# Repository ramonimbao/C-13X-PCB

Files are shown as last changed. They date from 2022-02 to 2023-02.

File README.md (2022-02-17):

# C-13X-PCB

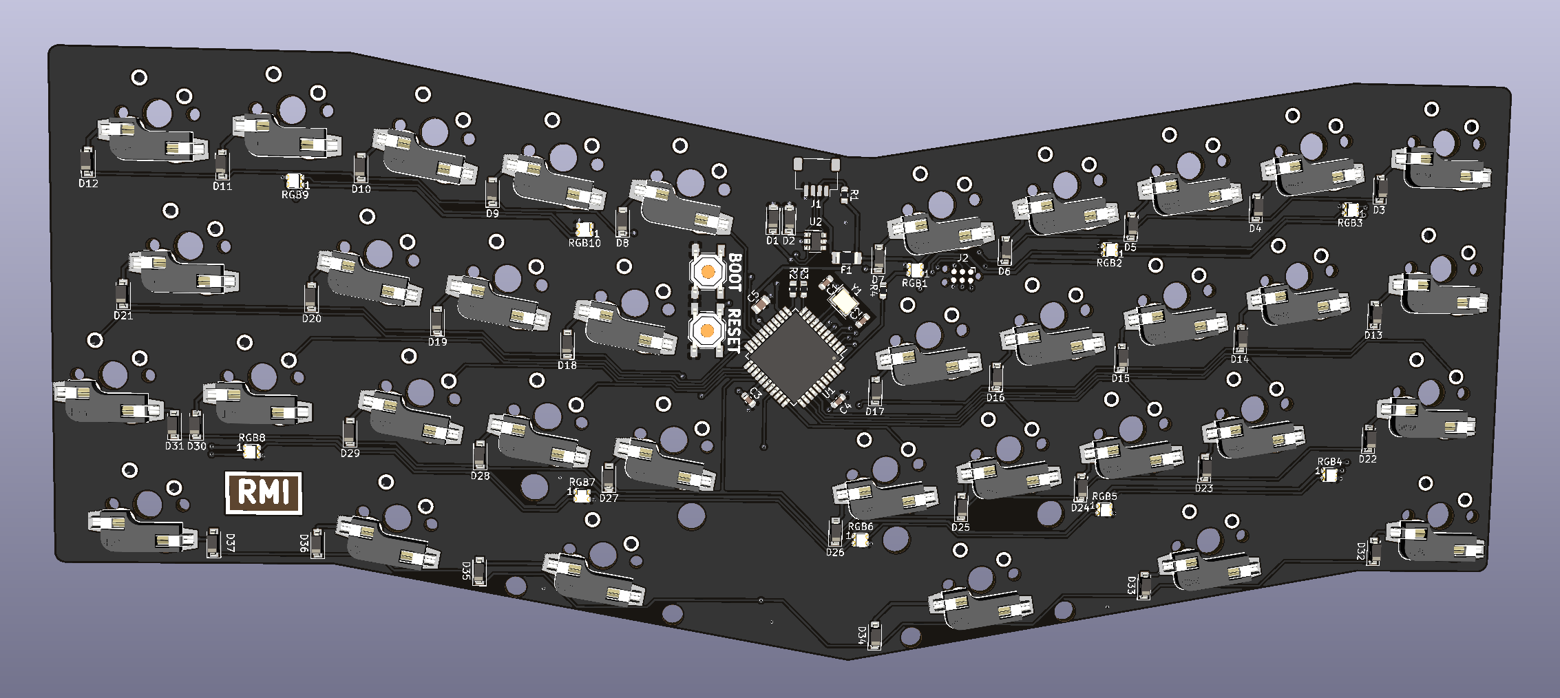
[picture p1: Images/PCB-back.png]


## Features

- ATmega32A
- ai03 daughterboard compatible
- Solder and Kailh hotswap compatible

## How to order

1. JLCPCB.com
2. Upload the gerber zip file from the `Gerbers` directory.
3. Select SMT assembly as an option.
4. Select the bottom side to assemble.
5. Upload the BOM and CPL files from the `JLCPCB` directory.
6. Place your order.
7. ???
8. Profit!

## After ordering

Once you've received the boards, you will have to flash a bootloader on it before being able to flash any QMK firmware on it.

Instructions for that can be found using [here](https://github.com/coseyfannitutti/discipline/blob/master/doc/bootloader/README.md).

## Flashing QMK firmware on it

TBD because I've yet to order boards for myself

## License

This has the same license as the C-13X. See the `LICENSE` file for more details.

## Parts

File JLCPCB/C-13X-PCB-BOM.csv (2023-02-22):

Comment | Designator | Footprint | LCSC
22pF | C1,C2 | Capacitor_SMD:C_0603_1608Metric | C1653
100nF | C3,C4 | Capacitor_SMD:C_0603_1608Metric | C14663
10uF | C5 | Capacitor_SMD:C_0805_2012Metric | C15850
3.6V | D1,D2 | Diode_SMD:D_SOD-123 | C2891771
1N4148W | D3,D4,D5,D6,D7,D8,D9,D10,D11,D12,D13,D14,D15,D16,D17,D18,D19,D20,D21,D22,D23,D24,D25,D26,D27,D28,D29,D30,D31,D32,D33,D34,D35,D36,D37 | Diode_SMD:D_SOD-123 | C81598
500mA | F1 | Fuse:Fuse_1206_3216Metric_Pad1.42x1.75mm_HandSolder | C69688
ai03_Daughterboard_Connector | J1 | Connector_JST:JST_SH_SM04B-SRSS-TB_1x04-1MP_P1.00mm_Horizontal | C160404
MX-NoLED | MX11,MX12,MX13,MX14,MX15,MX16,MX17,MX18,MX19,MX20,MX31,MX32,MX33,MX34,MX35,MX36,MX37,MX50,MX51,MX52,MX53,MX54,MX55,MX56,MX58,MX66,MX69 | MX_HS:MXOnly-1U-Hotswap-NoLED | C5156480
MX-NoLED | MX30,MX57 | MX_HS:MXOnly-1.25U-Hotswap-NoLED | C5156480
MX-NoLED | MX38,MX49 | MX_HS:MXOnly-1.75U-Hotswap-NoLED | C5156480
MX-NoLED | MX65,MX70 | MX_HS:MXOnly-1.5U-Hotswap-NoLED | C5156480
MX-NoLED | MX67 | MX_HS:MXOnly-2.75U-Hotswap-NoLED | C5156480
MX-NoLED | MX68 | MX_HS:MXOnly-2.25U-Hotswap-NoLED | C5156480
1.5k | R1 | Resistor_SMD:R_0603_1608Metric | C22843
75 | R2,R3 | Resistor_SMD:R_0603_1608Metric | C4275
470 | R4 | Resistor_SMD:R_0603_1608Metric | C23179
WS2812B-2020 | RGB1,RGB2,RGB3,RGB4,RGB5,RGB6,RGB7,RGB8,RGB9,RGB10 | random-keyboard-parts:WS2812B-2020 | C965555
SW_Push | SW1,SW2 | Button_Switch_SMD:SW_SPST_TL3342 | C318884
ATmega32A-AU | U1 | Package_QFP:TQFP-44_10x10mm_P0.8mm | C5659
SRV05-4 | U2 | Package_TO_SOT_SMD:SOT-23-6 | C85364
Crystal_GND24_Small | Y1 | Crystal:Crystal_SMD_3225-4Pin_3.2x2.5mm | C13738

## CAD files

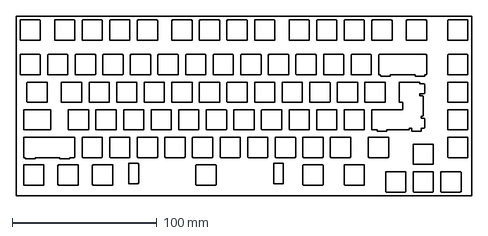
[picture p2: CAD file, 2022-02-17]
layout.dxf
314.3 x 123.8 mm

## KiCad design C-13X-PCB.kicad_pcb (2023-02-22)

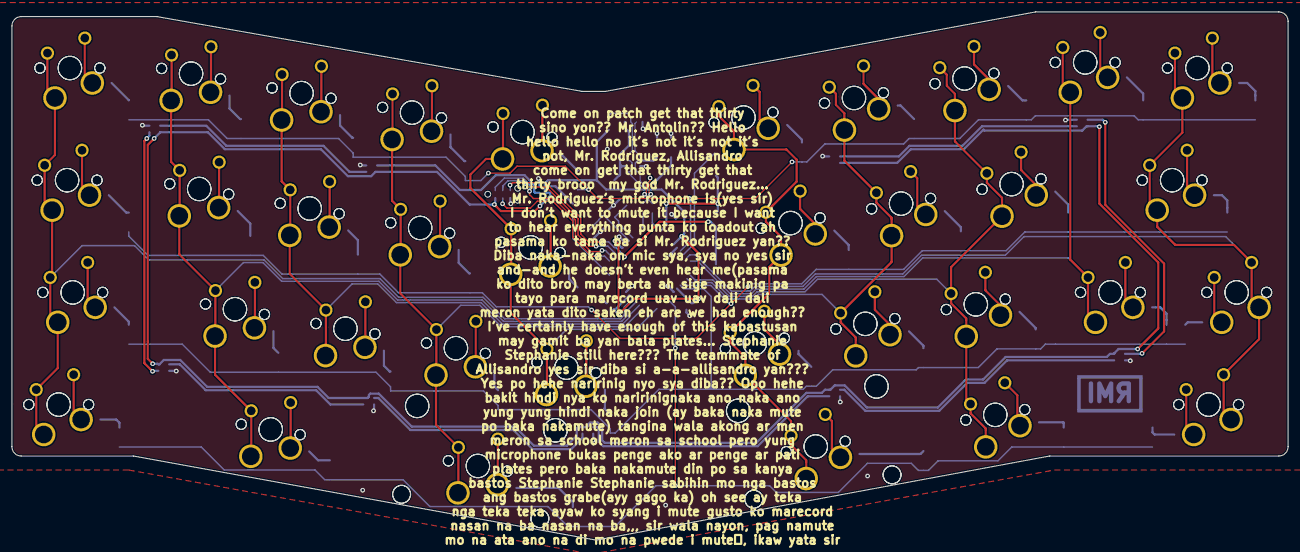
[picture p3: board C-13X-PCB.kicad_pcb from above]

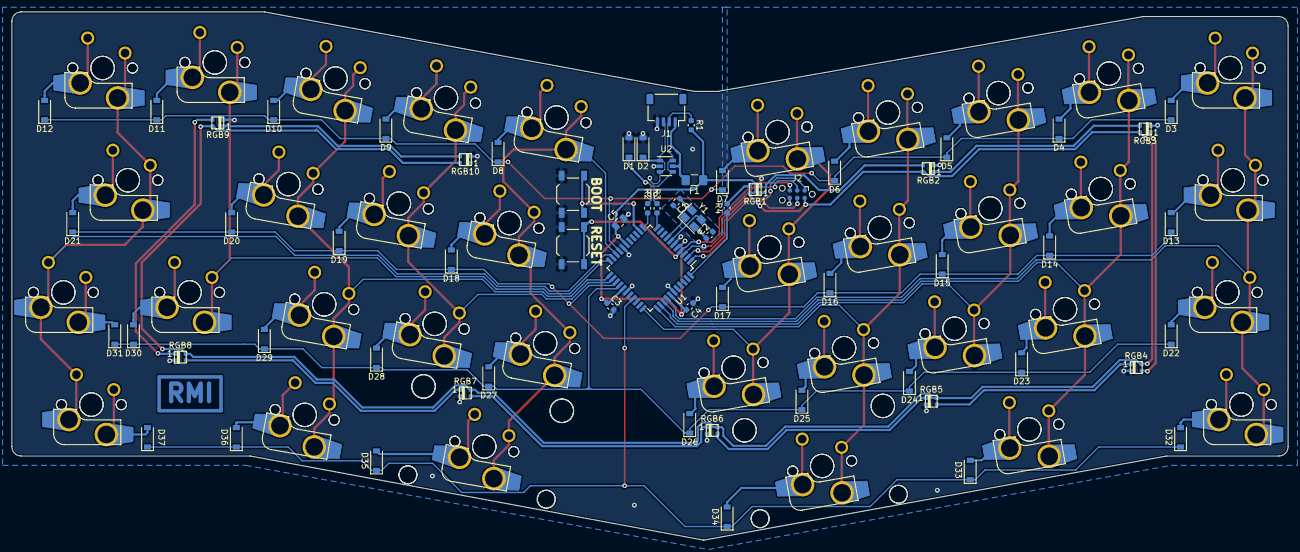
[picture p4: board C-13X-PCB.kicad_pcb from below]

Board: 2 copper layers, 216.7 x 89.7 mm, 135 parts (100 on the bottom side), 74 nets.

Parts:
C1, C2: 22pF; C_0603_1608Metric
C3, C4: 100nF; C_0603_1608Metric
C5: 10uF; C_0805_2012Metric
D1, D2: 3.6V; D_SOD-123
D3, D4, D5, D6, D7, D8, D9, D10, D11, D12, D13, D14, D15, D16, D17, D18, D19, D20, D21, D22, D23, D24, D25, D26, D27, D28, D29, D30, D31, D32, D33, D34, D35, D36, D37: 1N4148; D_SOD-123
F1: 500mA; Fuse_1206_3216Metric_Pad1.42x1.75mm_HandSolder
G1: Signature
J1: ai03_Daughterboard_Connector; JST_SH_SM04B-SRSS-TB_1x04-1MP_P1.00mm_Horizontal
J2: AVR-TagConnect; Tag-Connect_TC2030-IDC-NL_2x03_P1.27mm_Vertical
MX1, MX2, MX3, MX4, MX5, MX6, MX7, MX8, MX9, MX10, MX22, MX23, MX24, MX25, MX26, MX27, MX28, MX40, MX41, MX42, MX43, MX44, MX45, MX46, MX48, MX60, MX63: MX-NoLED; MXOnly-1U-NoLED
MX11, MX12, MX13, MX14, MX15, MX16, MX17, MX18, MX19, MX20, MX31, MX32, MX33, MX34, MX35, MX36, MX37, MX50, MX51, MX52, MX53, MX54, MX55, MX56, MX58, MX66, MX69: MX-NoLED; MXOnly-1U-Hotswap-NoLED
MX21, MX47: MX-NoLED; MXOnly-1.25U-NoLED
MX29, MX39: MX-NoLED; MXOnly-1.75U-NoLED
MX30, MX57: MX-NoLED; MXOnly-1.25U-Hotswap-NoLED
MX38, MX49: MX-NoLED; MXOnly-1.75U-Hotswap-NoLED
MX59, MX64: MX-NoLED; MXOnly-1.5U-NoLED
MX61: MX-NoLED; MXOnly-2.75U-ReversedStabilizers-NoLED
MX62: MX-NoLED; MXOnly-2.25U-ReversedStabilizers-NoLED
MX65, MX70: MX-NoLED; MXOnly-1.5U-Hotswap-NoLED
MX67: MX-NoLED; MXOnly-2.75U-Hotswap-NoLED
MX68: MX-NoLED; MXOnly-2.25U-Hotswap-NoLED
R1: 1.5k; R_0603_1608Metric
R2, R3: 75; R_0603_1608Metric
R4: 470; R_0603_1608Metric
RGB1, RGB2, RGB3, RGB4, RGB5, RGB6, RGB7, RGB8, RGB9, RGB10: WS2812B-2020
SW1, SW2: SW_Push; SW_SPST_TL3342
U1: ATmega32A-AU; TQFP-44_10x10mm_P0.8mm
U2: SRV05-4; SOT-23-6
Y1: Crystal_GND24_Small; Crystal_SMD_3225-4Pin_3.2x2.5mm

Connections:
+5V: C3.1, C4.1, C5.1, F1.1, J2.2, R1.2, RGB1.4, RGB2.4, RGB3.4, RGB4.4, RGB5.4, RGB6.4, RGB7.4, RGB8.4, RGB9.4, RGB10.4, U1.5, U1.17, U1.27, U1.38
/A0: MX1.1, MX11.2, MX21.1, MX30.2, MX39.1, MX49.2, MX59.1, MX65.2, U1.37
/A1: MX2.1, MX12.2, MX22.1, MX31.2, MX40.1, MX50.2, MX60.1, MX66.2, U1.36
/A2: MX3.1, MX13.2, MX23.1, MX32.2, MX41.1, MX51.2, U1.35
/A3: MX4.1, MX14.2, MX24.1, MX33.2, MX42.1, MX52.2, MX61.1, MX67.2, U1.34
/A4: MX5.1, MX15.2, MX25.1, MX34.2, MX43.1, MX53.2, U1.33
/A7: D32.1, D33.1, D34.1, D35.1, D36.1, D37.1, U1.30
/C0: D3.1, D4.1, D5.1, D6.1, D7.1, D8.1, D9.1, D10.1, D11.1, D12.1, U1.19
/C1: MX6.1, MX16.2, MX26.1, MX35.2, MX44.1, MX54.2, MX62.1, MX68.2, U1.20
/C2: MX10.1, MX20.2, MX29.1, MX38.2, MX48.2, MX58.1, MX64.2, MX70.1, U1.21
/C3: MX9.1, MX19.2, MX47.1, MX57.2, U1.22
/C4: MX8.1, MX18.2, MX28.1, MX37.2, MX46.1, MX56.2, MX63.1, MX69.2, U1.23
/C5: MX7.1, MX17.2, MX27.1, MX36.2, MX45.1, MX55.2, U1.24
/C6: D13.1, D14.1, D15.1, D16.1, D17.1, D18.1, D19.1, D20.1, D21.1, U1.25
/C7: D22.1, D23.1, D24.1, D25.1, D26.1, D27.1, D28.1, D29.1, D30.1, D31.1, U1.26
/DBUS+: D2.1, J1.3, R3.1, U2.1, U2.3
/DBUS-: D1.1, J1.2, R1.1, R2.2, U2.4, U2.6
/Underglow/RGB: R4.2, RGB1.3
/XTAL+: C2.2, U1.7, Y1.3
/XTAL-: C1.2, U1.8, Y1.1
BOOT: SW2.2, U1.13
D+: R3.2, U1.11
D-: R2.1, U1.12
GND: C1.1, C2.1, C3.2, C4.2, C5.2, D1.2, D2.2, J1.4, J2.6, RGB1.2, RGB2.2, RGB3.2, RGB4.2, RGB5.2, RGB6.2, RGB7.2, RGB8.2, RGB9.2, RGB10.2, SW1.1, SW2.1, U1.6, U1.18, U1.28, U1.39, U2.2, Y1.2, Y1.4
MISO: J2.1, U1.2
MOSI: J2.4, U1.1
NRST: J2.5, SW1.2, U1.4
unnamed: D3.2, MX1.2, MX11.1
unnamed: D4.2, MX2.2, MX12.1
unnamed: D5.2, MX3.2, MX13.1
unnamed: D6.2, MX4.2, MX14.1
unnamed: D7.2, MX5.2, MX15.1
unnamed: D8.2, MX6.2, MX16.1
unnamed: D9.2, MX7.2, MX17.1
unnamed: D10.2, MX8.2, MX18.1
unnamed: D11.2, MX9.2, MX19.1
unnamed: D12.2, MX10.2, MX20.1
unnamed: D13.2, MX21.2, MX30.1
unnamed: D14.2, MX22.2, MX31.1
unnamed: D15.2, MX23.2, MX32.1
unnamed: D16.2, MX24.2, MX33.1
unnamed: D17.2, MX25.2, MX34.1
unnamed: D18.2, MX26.2, MX35.1
unnamed: D19.2, MX27.2, MX36.1
unnamed: D20.2, MX28.2, MX37.1
unnamed: D21.2, MX29.2, MX38.1
unnamed: D22.2, MX39.2, MX49.1
unnamed: D23.2, MX40.2, MX50.1
unnamed: D24.2, MX41.2, MX51.1
unnamed: D25.2, MX42.2, MX52.1
unnamed: D26.2, MX43.2, MX53.1
unnamed: D27.2, MX44.2, MX54.1
unnamed: D28.2, MX45.2, MX55.1
unnamed: D29.2, MX46.2, MX56.1
unnamed: D30.2, MX47.2, MX57.1
unnamed: D31.2, MX48.1, MX58.2
unnamed: D32.2, MX59.2, MX65.1
unnamed: D33.2, MX60.2, MX66.1
unnamed: D34.2, MX61.2, MX67.1
unnamed: D35.2, MX62.2, MX68.1
unnamed: D36.2, MX63.2, MX69.1
unnamed: D37.2, MX64.1, MX70.2
unnamed: RGB1.1, RGB2.3
unnamed: RGB2.1, RGB3.3
unnamed: RGB3.1, RGB4.3
unnamed: RGB4.1, RGB5.3
unnamed: RGB5.1, RGB6.3
unnamed: RGB6.1, RGB7.3
unnamed: RGB7.1, RGB8.3
unnamed: RGB8.1, RGB9.3
unnamed: RGB9.1, RGB10.3
RGB: R4.1, U1.44
SCLK: J2.3, U1.3
VBUS: F1.2, J1.1, U2.5
